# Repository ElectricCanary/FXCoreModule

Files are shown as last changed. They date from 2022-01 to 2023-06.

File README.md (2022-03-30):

# FXCoreModule

FXCore Module is a very compact development board for the Experimental Noize FXCore DSP.

It's breadboard friendly and easily incorporated on a PCB. It's in a stereo configuration and the converter chips are CS4344 and CS5343.

You'll find the full documentation, ECAD libraries and the source code for the program selector used to select from the 16 program with a single pot.

Website: [https://electric-canary.com/fxcoremodule](https://electric-canary.com/fxcoremodule)

Email: contact@electric-canary.com



The Code, Schematic and PCB manufacturing files are shared under a BY-NC-SA Creative Commons License

Go here for complete license : https://creativecommons.org/licenses/by-nc-sa/4.0/legalcode

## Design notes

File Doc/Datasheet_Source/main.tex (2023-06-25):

\documentclass[a4paper, 10pt]{article}

\usepackage[default]{comfortaa}
\usepackage[utf8]{inputenc}
\usepackage[english]{babel}
\usepackage{graphicx}
\usepackage{pdflscape}
\usepackage{geometry}
\usepackage{titlesec}
\usepackage{multicol}
\usepackage{lastpage}
\usepackage{fancyhdr}
\usepackage{array}
\usepackage{multirow, hhline}
\usepackage[table]{xcolor}
\usepackage[hidelinks]{hyperref}
\usepackage{textcomp}

\setlength{\columnseprule}{1pt}
\setlength{\columnsep}{1cm}

\definecolor{lightgray}{gray}{0.85}

\setlength{\arrayrulewidth}{0.35mm}
\setlength{\tabcolsep}{10pt}
\renewcommand{\arraystretch}{1.7}

\fancypagestyle{plain}{%
\fancyhf{} % clear all header and footer fields
\cfoot{\thepage /\pageref{LastPage}}
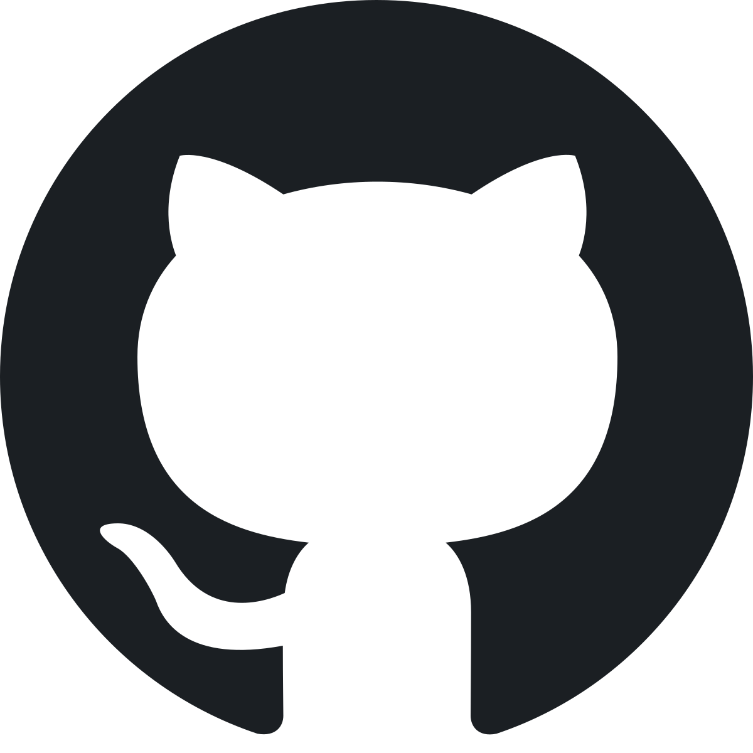
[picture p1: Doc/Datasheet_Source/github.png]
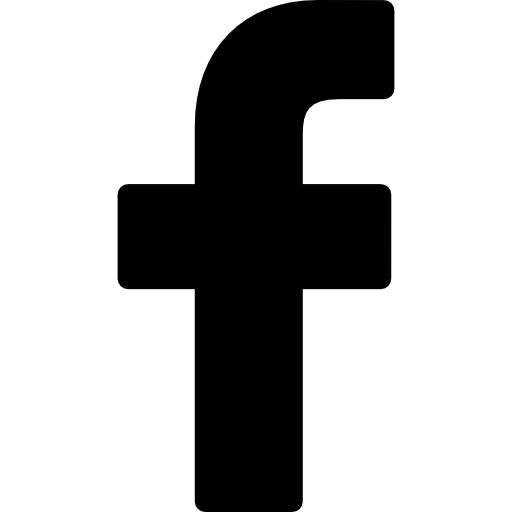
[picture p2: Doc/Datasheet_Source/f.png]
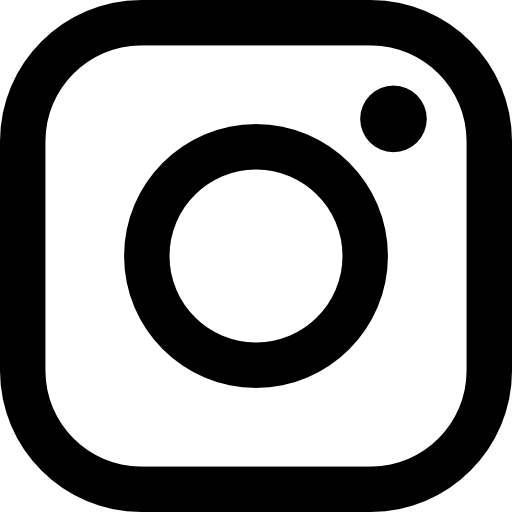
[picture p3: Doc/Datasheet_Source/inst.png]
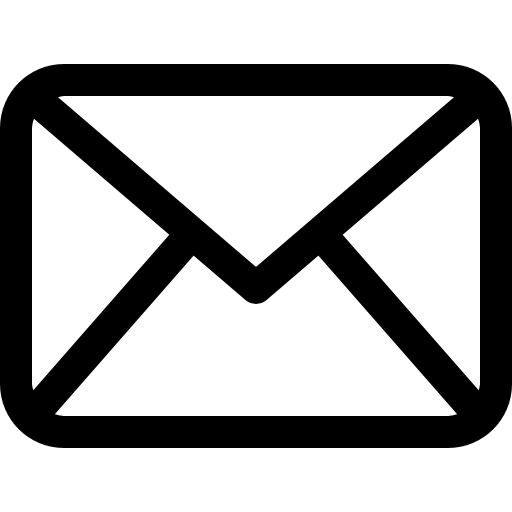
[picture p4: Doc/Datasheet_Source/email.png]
\rfoot{\href{https://github.com/ElectricCanary/FXCoreModule}{}\hspace{8pt}\href{https://www.facebook.com/ElectricCanary}{}\hspace{8pt}\href{https://www.instagram.com/electricanary/}{}\hspace{12pt}\href{mailto:support@electric-canary.com}{}}
\lfoot{\textcolor{black!70}{{\footnotesize\textcopyright Electric Canary - January 2021}}}
\renewcommand{\headrulewidth}{0pt}
\renewcommand{\footrulewidth}{0pt}}

\pagestyle{fancy}
\renewcommand{\headrulewidth}{0pt}
\cfoot{}
\cfoot{\thepage /\pageref{LastPage}}
\rfoot{\href{https://github.com/ElectricCanary/FXCoreModule}{}\hspace{8pt}\href{https://www.facebook.com/ElectricCanary}{}\hspace{8pt}\href{https://www.instagram.com/electricanary/}{}\hspace{12pt}\href{mailto:support@electric-canary.com}{}}
\lfoot{\textcolor{black!70}{{\footnotesize\textcopyright Electric Canary - January 2022}}}
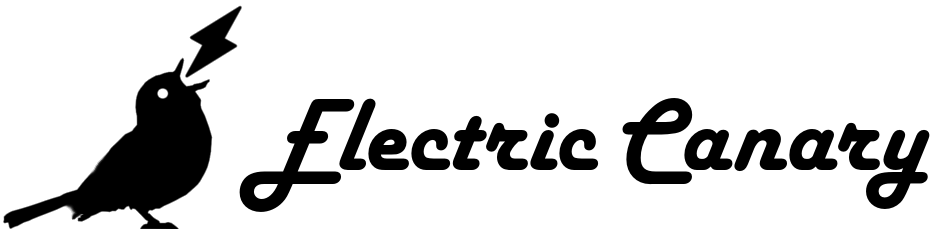
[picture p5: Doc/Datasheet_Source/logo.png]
\rhead{\href{https://electric-canary.com/bontempo}{}}
\lhead{\textbf{{\small\emph{\textcolor{black!70}{FXCore Module-Datasheet}}}}}

\titleformat*{\section}{\huge\bfseries}
\titleformat*{\subsection}{\LARGE\bfseries}
\titleformat*{\subsubsection}{\Large\bfseries}

\geometry{hmargin=2.5cm,vmargin=2.5cm}
\headheight=35pt

\begin{document}\thispagestyle{plain}
\begin{center}
\begin{Huge}
\vspace*{0.5cm}
\textbf{FXCore Module - Datasheet}
\rule {0.95\textwidth}{2pt}\\
\end{Huge}
\vspace{1cm}
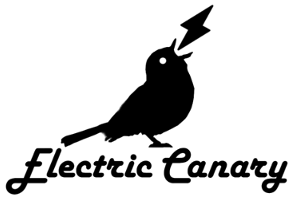
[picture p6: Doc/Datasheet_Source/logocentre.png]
\\
\vspace{1cm}
\end{center}

\begin{multicols}{2}
\section{Introduction}
\bigbreak
FXCore Module is an extremely compact stereo development board for the Experimental Noize FXCore DSP. It makes the FXCore breadboard friendly and easily incorporated in a project.\\

The power module assures very efficient power delivery for a very large range of input voltage. The micro-controller allows for a very easy program selection with a single potentiometer.\\

The FXCore Module opens the door to a world of powerful DSP effects with a plethora of controls.
\vfill\null
\columnbreak

\section{Features}
\bigbreak
\begin{itemize}
\item Stereo Line In \& Out
\item Onboard 5V to 3V3 Onboard Linear Regulator
\item Easy Analog Program Selection
\item Onboard Clipping LED
\item Extremely Compact Design
\item Breadboard Compatible
\item Easy Access to Tap-Tempo, Bypass \& User Outputs
\end{itemize}
\end{multicols}

\newpage
\headheight=35pt
\tableofcontents
\newpage

\section{Pin Configuration}
\label{sec:pinconfig}
\begin{center}
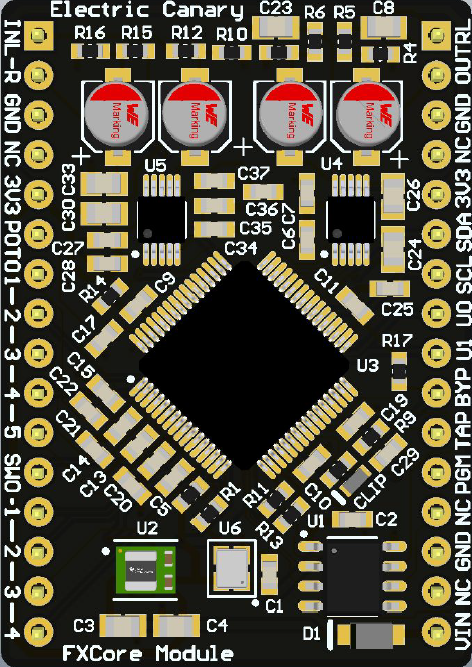
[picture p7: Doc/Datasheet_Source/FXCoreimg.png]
\\
\begin{table}[h!]
{\rowcolors{1}{}{lightgray!50}
\begin{tabular}{|m{0.5cm}|m{4.5cm}|m{0.7cm}|m{7.5cm}|}
\hline
\rowcolor{gray} \centering \textcolor{white}{\Large\textbf{N°}} & \centering \textcolor{white}{\Large\textbf{Name}} & \centering \textcolor{white}{\Large\textbf{I/O}} & \textcolor{white}{\Large\textbf{Description}}\\
\hline
\centering 1 & \centering INL & \centering I & Left Line Audio Input\\
\hline
\centering 2 & \centering INR & \centering I & Right Line Audio Input\\
\hline
\centering 3 & \centering GND & \centering I & Ground\\
\hline
\centering 4 & \centering NC & \centering X & Not Connected\\
\hline
\centering 5 & \centering 3V3 & \centering I & +3.3V Power Input\\
\hline
\centering 6 & \centering POT0 & \centering I & Analog Input for Potentiometer 0\\
\hline
\centering 7 & \centering POT1 & \centering I & Analog Input for Potentiometer 1\\
\hline
\centering 8 & \centering POT2 & \centering I & Analog Input for Potentiometer 2\\
\hline
\centering 9 & \centering POT3 & \centering I & Analog Input for Potentiometer 3\\
\hline
\centering 10 & \centering POT4 & \centering I & Analog Input for Potentiometer 4\\
\hline
\centering 11 & \centering POT5 & \centering I & Analog Input for Potentiometer 5\\
\hline
\centering 12 & \centering SW0 & \centering I & Digital Input for Switch 0\\
\hline
\centering 13 & \centering SW1 & \centering I & Digital Input for Switch 1\\
\hline
\centering 14 & \centering SW2 & \centering I & Digital Input for Switch 2\\
\hline
\centering 15 & \centering SW3 & \centering I & Digital Input for Switch 3\\
\hline
\centering 16 & \centering SW4 & \centering I & Digital Input for Switch 4\\
\hline
\end{tabular}}
\caption{Pin Configuration}
\end{table}
\begin{table}[h!]
{\rowcolors{1}{}{lightgray!50}
\begin{tabular}{|m{0.5cm}|m{4.5cm}|m{0.7cm}|m{7.5cm}|}
\hline
\rowcolor{gray} \centering \textcolor{white}{\Large\textbf{N°}} & \centering \textcolor{white}{\Large\textbf{Name}} & \centering \textcolor{white}{\Large\textbf{I/O}} & \textcolor{white}{\Large\textbf{Description}}\\
\hline
\centering 17 & \centering VIN & \centering I & 5V Linear Regulator Input\\
\hline
\centering 18 & \centering NC & \centering X & Not Connected\\
\hline
\centering 19 & \centering GND & \centering I & Ground\\
\hline
\centering 20 & \centering NC & \centering I/O & Not Connected in Normal Operation (UPDI Pin of U1)\\
\hline
\centering 21 & \centering PGM & \centering I & Analog Input for Selecting one of the 16 Programs\\
\hline
\centering 22 & \centering TAP & \centering I & Digital Input for Tap Tempo\\
\hline
\centering 23 & \centering BYP & \centering I & Digital Input for Bypass\\
\hline
\centering 24 & \centering U1 & \centering O & Digital User 1 Output \\
\hline
\centering 25 & \centering U0 & \centering O & Digital User 0 Output\\
\hline
\centering 26 & \centering SCL & \centering I/O & Serial Clock Wire of the FXCore I2C Programming Bus\\
\hline
\centering 27 & \centering SDA & \centering I/O & Serial Data Wire of the FXCore I2C Programming Bus\\
\hline
\centering 28 & \centering 3V3 & \centering I & +3.3V Power Input\\
\hline
\centering 29 & \centering NC & \centering X & Not Connected\\
\hline
\centering 30 & \centering GND & \centering I & Ground\\
\hline
\centering 31 & \centering OUTR & \centering O & Right Line Audio Output\\
\hline
\centering 32 & \centering OUTL & \centering O & Left Line Audio Output\\
\hline
\end{tabular}}
\caption{Pin Configuration (continued)}
\end{table}
\end{center}
\newpage

\section{Absolute Maximum Ratings}
\begin{table}[h!]
\centering
{\rowcolors{1}{}{lightgray!50}
\begin{tabular}{|c|c|c|c|}
\hline
\rowcolor{gray}\textcolor{white}{\Large\textbf{Parameter}} & \textcolor{white}{\Large\textbf{Min}} & \textcolor{white}{\Large\textbf{Max}} & \textcolor{white}{\Large\textbf{Unit}}\\
\hline
Storage Temperature & -40 & +140 & °C\\
\hline
Operating Temperature & -30 & +80 & °C\\
\hline
+3.3V Voltage & -0.3 & +6 & V\\
\hline
VIn Voltage & -0.3 & +6.5 & V\\
\hline
Audio Line In Voltage & -0.7 & +7 & V\\
\hline
Audio Line In Current & -10 & +10 & mA\\
\hline
PGM Pin Voltage & -0.5 & +3.8 & V\\
\hline
PGM Pin Current & -40 & +40 & mA\\
\hline
\end{tabular}}
\caption{Absolute Maximum Ratings}
\end{table}

\section{Characteristics}
\bigbreak
\begin{table}[h!]
\centering
\begin{tabular}{|c|c|c|c|c|}
\hline
\rowcolor{gray}\textcolor{white}{\Large\textbf{Parameter}} & \textcolor{white}{\Large\textbf{Min}} &  \textcolor{white}{\Large\textbf{Typ.}} & \textcolor{white}{\Large\textbf{Max}} & \textcolor{white}{\Large\textbf{Unit}}\\
\hline
3.3V Power Supply & 3.2 & 3.3 & 3.42 & V\\
\hline
VIn Power Supply & 4 & 5 & 6 & V\\
\hline
3.3V Current & - & 155 & - & mA\\
\hline
Power Module Supply Switching Frequency & 675 & 750 & 825 & kHz\\
\hline
POT0 – POT5 source impedance & - & - & 10 & k$\Omega$\\
\hline
Input low voltage to SWO – SW4, ENABLE and TAP & GND & - & 0.66 & V\\
\hline
Input high voltage to SWO – SW4, ENABLE and TAP & 2.64 & - & 3.3 & V\\
\hline
Output low voltage to USER0 \& USER1 & 0 & - & 0.4 & V\\
\hline
Output high voltage to USER0 \& USER1 & 2.4 & - & 3.3 & V\\
\hline
Estimated FLASH endurance (Erase/Write cycles) & - & 10 000 & - & -\\
\hline
Sample rate range & 9.766 & 48 & 48.046 & kHz\\
\hline
Dynamic Range & 86 & 94 & - & dBA\\
\hline
Full Scale Input Voltage & 3.7 & 3.75 & 3.8 & Vpp\\
\hline
Full Scale Output Voltage & 2 & 2.15 & 2.3 & Vpp\\
\hline
\end{tabular}
\caption{Characteristics}
\end{table}

\begin{landscape}
\section{Typical Application Schematic}
\begin{center}

\end{center}
\end{landscape}
\newpage

\begin{landscape}
\section{Schematic}
\begin{center}

\end{center}
\end{landscape}
\newpage

\section{Bill of Materials}
{\rowcolors{1}{}{lightgray!50}
\begin{tabular}{|c|c|}
\hline
\rowcolor{gray}{\LARGE\textcolor{white}{\textbf{Name}}} &  {\LARGE\textcolor{white}{\textbf{Value}}}\\
\hline
R1 & 33$\Omega$\\
\hline
R3 & 47k$\Omega$ \\
\hline
R4, R7, R14, R17 & 10k$\Omega$ \\
\hline
R5, R6 & 470$\Omega$ \\
\hline
R8, R11, R13 & 330$\Omega$ \\
\hline
R9 & 100$\Omega$ \\
\hline
R10, R12, R15, R16 & 5.1k$\Omega$ \\
\hline
 &  \\
\hline
C1, C2, C6, C9, C10, C11, C13, C14, C15, C17, C18, C19, C20, C21, C22, C25, C27 & 100nF \\
\hline
C3, C24, C26 & 10$\mu$F \\
\hline
C4 & 47$\mu$F \\
\hline
C5, C7, C28, C35, C37 & 1$\mu$F \\
\hline
C8, C23 & 2.7nF \\
\hline
C12, C16, C31, C32 & 3.3$\mu$F \\
\hline
 &  \\
\hline
D1 & Schottky \\
\hline
D2 & LED \\
\hline
 &  \\
\hline
P1, P2 & 16 Pin Header \\
\hline
 &  \\
\hline
U1 & ATtiny202 \\
\hline
U2 & AP7365-33ERG-13 \\
\hline
U3 & FXCore \\
\hline
U4 & CS4344 \\
\hline
U5 & CS5343 \\
\hline
U6 & 12.288MHz Oscillator \\
\hline
\end{tabular}}
\newpage

\section{Assembly}
\begin{center}
\vfill

\vfill
\end{center}
\newpage

\section{Dimensions}
\vfill
\begin{center}

\end{center}
\vfill
\newpage

\end{document}

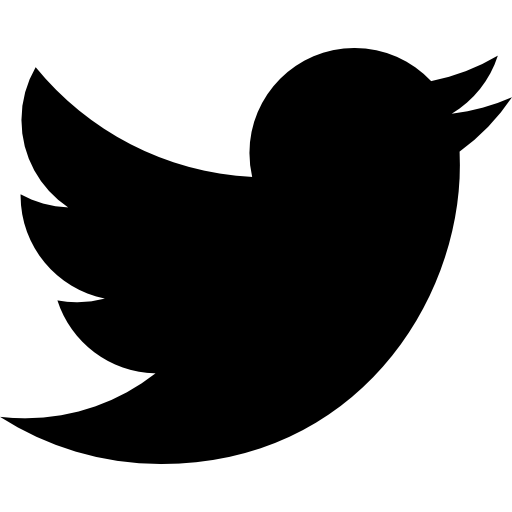
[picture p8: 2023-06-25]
Doc/Datasheet_Source/twitter.png

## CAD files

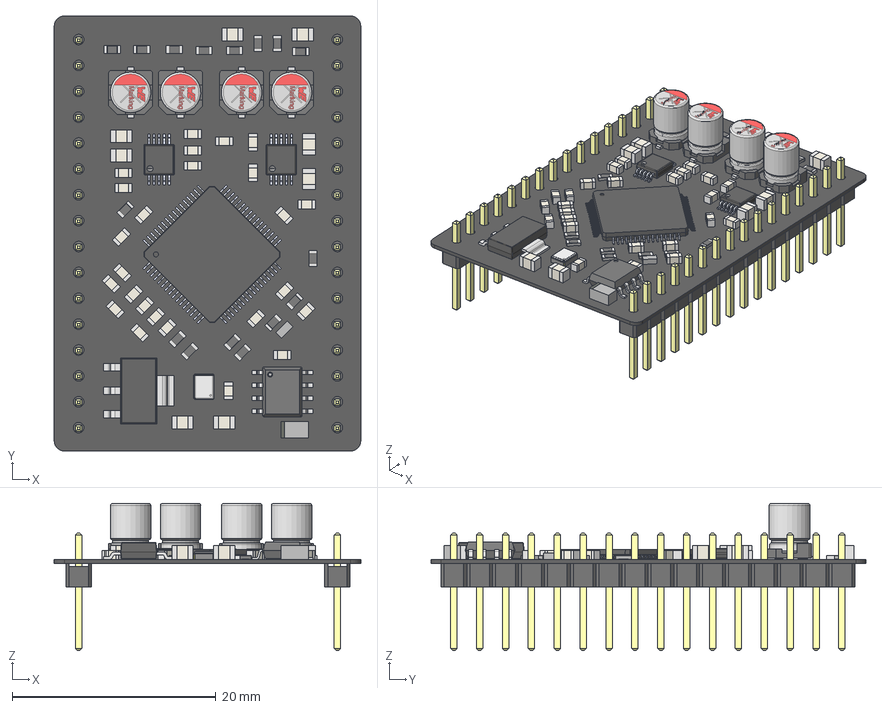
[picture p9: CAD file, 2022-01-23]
Doc/FXCore_Module.step
30.1 x 42.7 x 14.4 mm
User_Library-KXO-V95-1
Extruded x 102
User_Library-res0603-1 x 16
User_Library-TSSOP-10 x 2
User_Library-S-PQFP-G64
CircuitWorks-SOT-223
User_Library-so8-3
PinArray x 16
BodyArray x 16
capicitor_4x5.5x1 x 4
Base_\X2\03A6\X0\4Capacitor x 4

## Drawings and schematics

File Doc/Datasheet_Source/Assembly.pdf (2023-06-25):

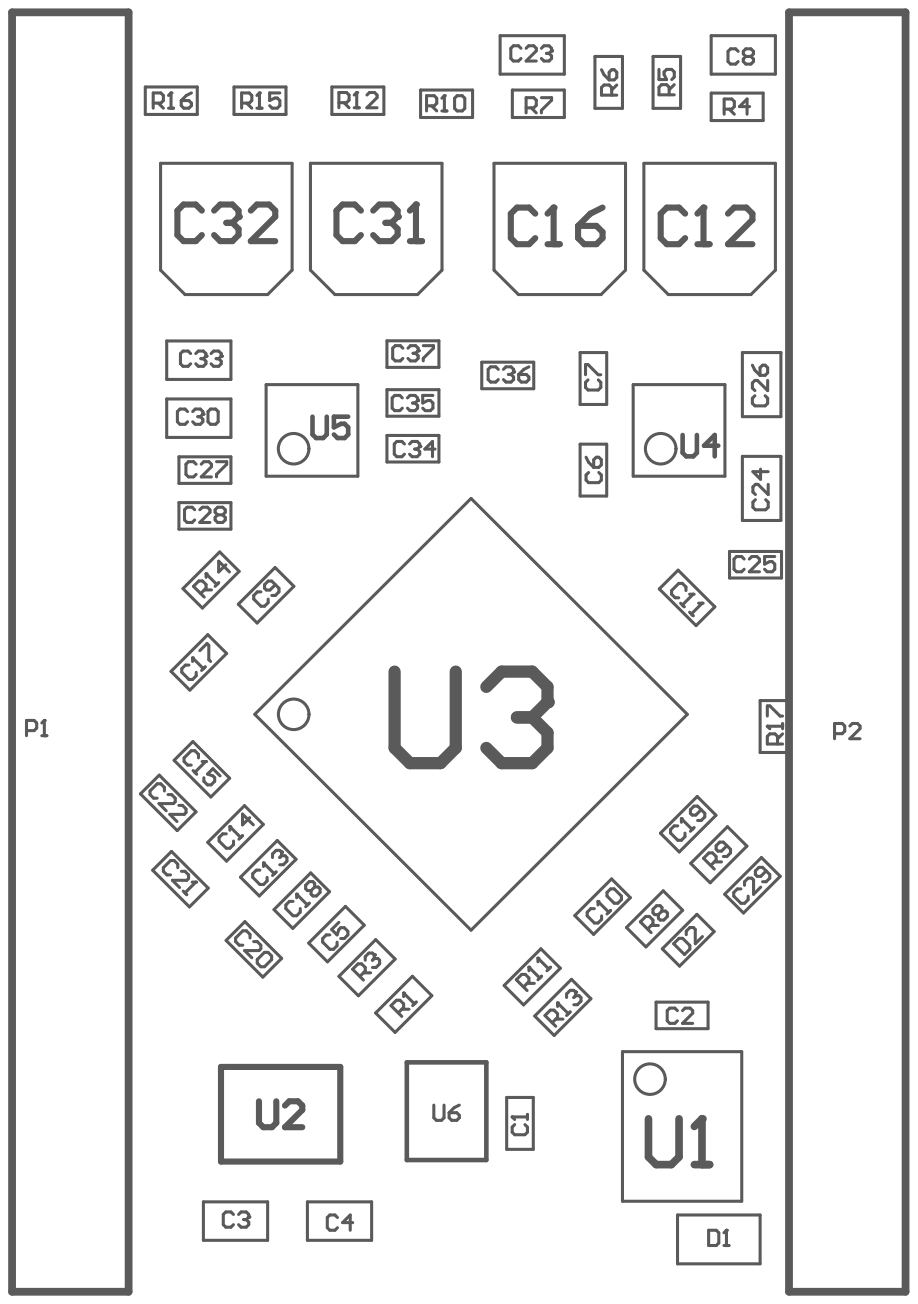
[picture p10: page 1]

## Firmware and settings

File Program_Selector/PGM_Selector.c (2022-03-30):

/*
 * FXCore_Module_Pgm_Selector.c
 *
 * Created: 06/12/2021 21:14:55
 * Author : Antoine Ricoux for Electric Canary
 
 This codeis  shared under a BY-NC-SA Creative Commons License
 Go here for complete license : https://creativecommons.org/licenses/by-nc-sa/4.0/legalcode
 
 For Attiny202
 Analog value to 4bit value converter to select one of 16 programs from a potentiometer.
 
 */ 

#include <avr/io.h>
#include <avr/interrupt.h>

#define PGM0_PIN 2
#define PGM1_PIN 3
#define PGM2_PIN 6
#define PGM3_PIN 7
#define POT_PIN 1

volatile uint8_t pot;
volatile uint8_t sw;

void IO_Init(void)
{
  //PGM pins as outputs
  VPORTA_DIR |= (1<<PGM0_PIN) | (1<<PGM1_PIN) | (1<<PGM2_PIN) | (1<<PGM3_PIN);
}

void ADC_Init(void)
{
  //Enable ADC, 8-bit, free running mode, VCC as ref
  ADC0_CTRLA |= ADC_ENABLE_bm | ADC_FREERUN_bm | ADC_RESSEL_bm;
  ADC0_CTRLC |= ADC_SAMPCAP_bm | ADC_REFSEL0_bm;
  //Enable result ready interrupt
  ADC0_INTCTRL |= ADC_RESRDY_bm;
  //Interrupts global enable
  sei();
  //Select Channel 1
  ADC0_MUXPOS = 1;
  //Start conversion
  ADC0_COMMAND |= ADC_STCONV_bm;
}

ISR(ADC0_RESRDY_vect)
{
  pot = ADC0_RESL>>4;
}

int main(void)
{
  //Run at 10MHz
  CLKCTRL_MCLKCTRLB = 0;
  IO_Init();
  ADC_Init();
  
    while (1) 
    {
    if(pot & 0b00000001)
    {
      VPORTA_OUT |= (1<<PGM0_PIN);
    }
    
    else
    {
      VPORTA_OUT &= ~(1<<PGM0_PIN);
    }
    
    if(pot & 0b00000010)
    {
      VPORTA_OUT |= (1<<PGM1_PIN);
    }
    
    else
    {
      VPORTA_OUT &= ~(1<<PGM1_PIN);
    }
    
    if(pot & 0b00000100)
    {
      VPORTA_OUT |= (1<<PGM2_PIN);
    }
    
    else
    {
      VPORTA_OUT &= ~(1<<PGM2_PIN);
    }
    
    if(pot & 0b00001000)
    {
      VPORTA_OUT |= (1<<PGM3_PIN);
    }
    
    else
    {
      VPORTA_OUT &= ~(1<<PGM3_PIN);
    }
    }
}
